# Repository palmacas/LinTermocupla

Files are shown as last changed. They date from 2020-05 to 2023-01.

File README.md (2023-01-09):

# LinTermocupla

LinTermocupla

The board reads the voltaje from a thermocouple (type J or K) and linearizes the temperature. The circuit is based on a PIC16F877a and includes a resistor-based digital-to-analog converter, so the linearized temperature value can be read by a PLC.

---
More information:  
[Linealizar una Termocupla [Spanish]](https://palmacas.com/linealizar-una-termocupla/)

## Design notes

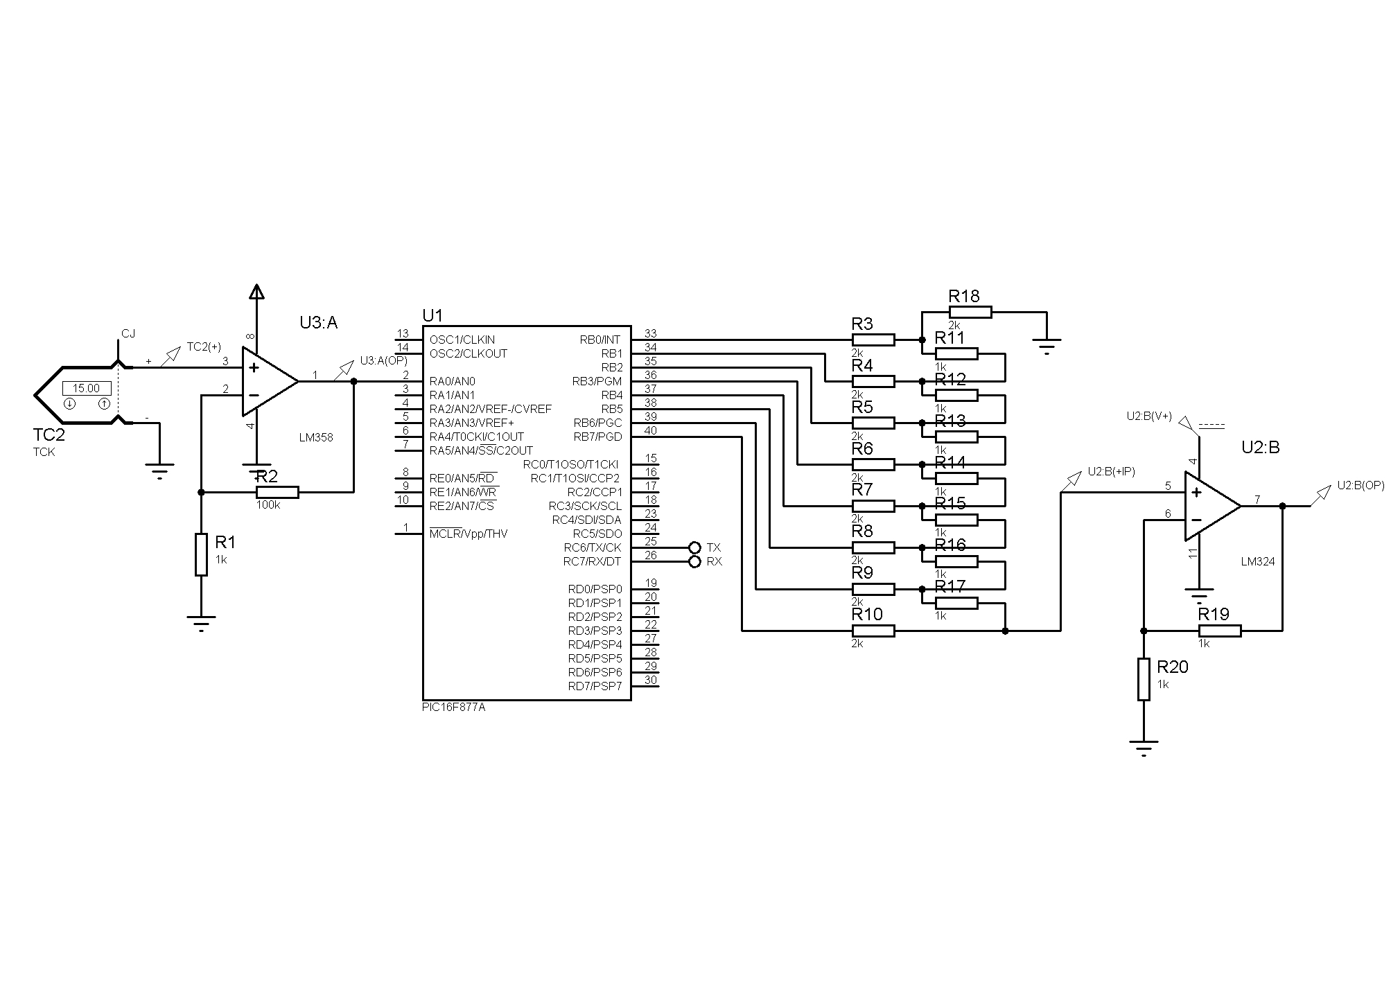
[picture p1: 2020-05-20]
simulation/lin_termocupla.jpg

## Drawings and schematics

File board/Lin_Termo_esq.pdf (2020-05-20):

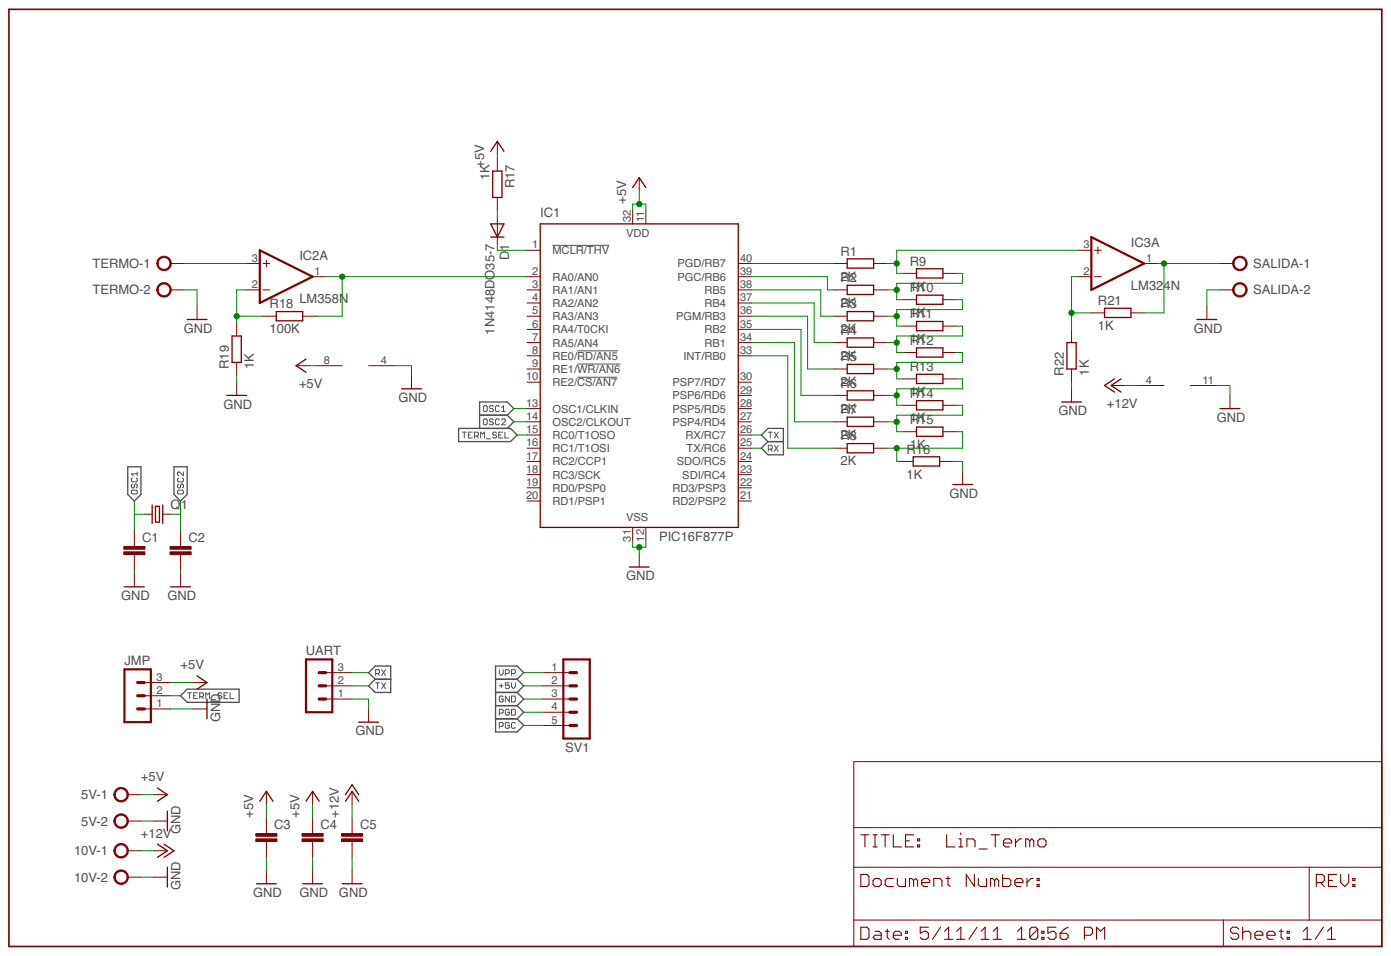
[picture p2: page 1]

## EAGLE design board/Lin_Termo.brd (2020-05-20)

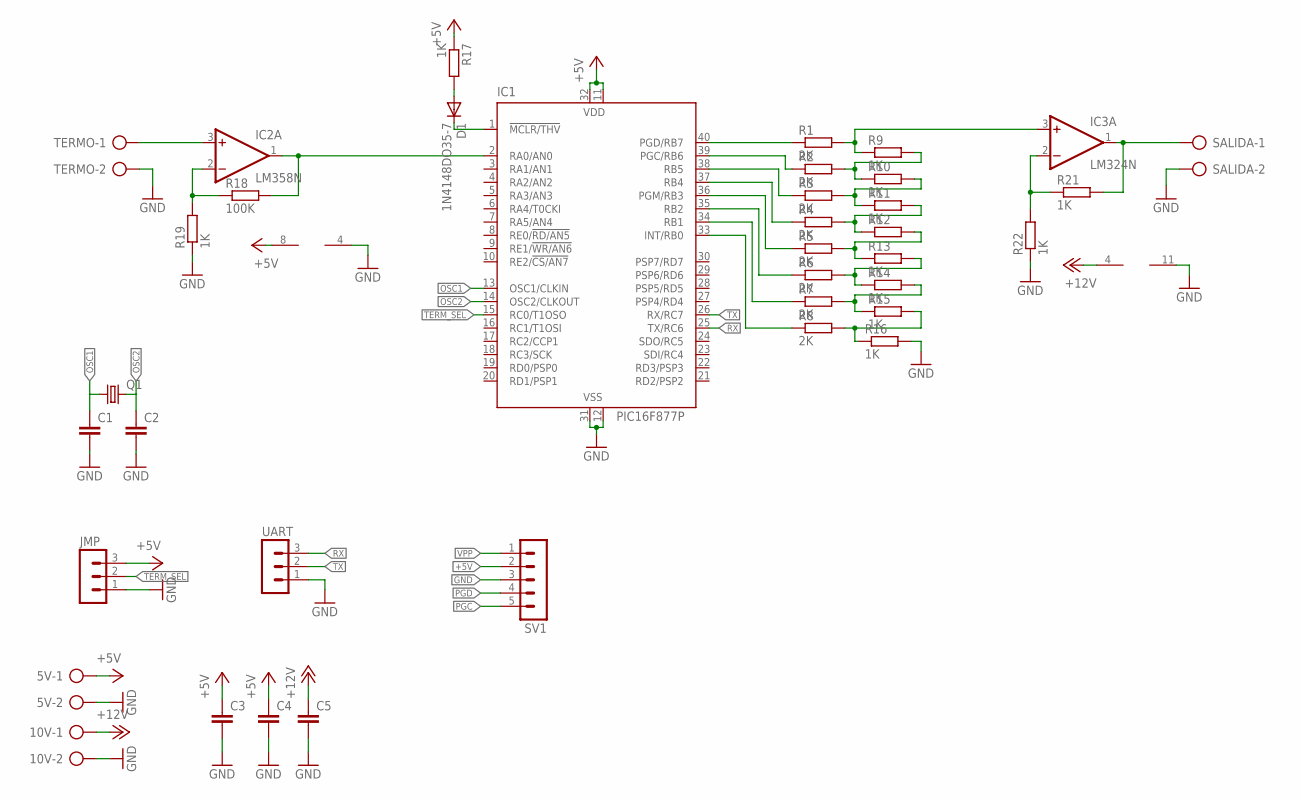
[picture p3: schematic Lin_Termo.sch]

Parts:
5V, 10V: AK500/2
C1, C2, C3, C4, C5: C-EU025-025X050; C025-025X050
D1: 1N4148DO35-7; DO35-7
IC1: PIC16F877P; DIL40
IC2: LM358N; DIL08
IC3: LM324N; DIL14
JMP: MA03-1
Q1: CRYSTALHC49S; HC49/S
R1, R2, R3, R4, R5, R6, R7, R8: 2K; 0207/2V
R9, R10, R11, R13, R14, R15, R16: 1K; 0207/2V
R12: R-EU_0207/2V; 0207/2V
R17, R19, R21, R22: 1K; 0207/7
R18: 100K; 0207/7
SALIDA: AK500/2
SV1: MA05-1
TERMO: AK500/2
UART: MA03-1

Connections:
+5V: 5V.1, C3.1, C4.1, IC1.11 (VDD), IC1.32 (VDD), IC2.8 (V+), JMP.3, R17.1, SV1.2
+12V: 10V.1, C5.1, IC3.4 (V+)
GND: 5V.2, 10V.2, C1.2, C2.2, C3.2, C4.2, C5.2, IC1.12 (VSS), IC1.31 (VSS), IC2.4 (V-), IC3.11 (V-), JMP.1, R16.2, R19.1, R22.1, SALIDA.2, SV1.3, TERMO.2, UART.1
unnamed: IC3.3 (+IN), R1.2, R9.1
unnamed: R2.2, R9.2, R10.1
unnamed: R3.2, R10.2, R11.1
unnamed: R4.2, R11.2, R12.1
unnamed: R5.2, R12.2, R13.1
unnamed: R6.2, R13.2, R14.1
unnamed: R7.2, R14.2, R15.1
unnamed: D1.A, R17.2
unnamed: IC1.38 (RB5), R3.1
unnamed: IC1.37 (RB4), R4.1
unnamed: IC1.36 (PGM/RB3), R5.1
unnamed: IC1.35 (RB2), R6.1
unnamed: IC1.34 (RB1), R7.1
unnamed: IC1.33 (INT/RB0), R8.1
unnamed: IC1.2 (RA0/AN0), IC2.1 (OUT), R18.2
unnamed: IC2.2 (-IN), R18.1, R19.2
unnamed: IC2.3 (+IN), TERMO.1
unnamed: R8.2, R15.2, R16.1
unnamed: IC3.2 (-IN), R21.1, R22.2
unnamed: IC3.1 (OUT), R21.2, SALIDA.1
OSC1: C1.1, IC1.13 (OSC1/CLKIN), Q1.1
OSC2: C2.1, IC1.14 (OSC2/CLKOUT), Q1.2
PGC: IC1.39 (PGC/RB6), R2.1, SV1.5
PGD: IC1.40 (PGD/RB7), R1.1, SV1.4
RX: IC1.25 (TX/RC6), UART.3
TERM_SEL: IC1.15 (RC0/T1OSO), JMP.2
TX: IC1.26 (RX/RC7), UART.2
VPP: D1.C, IC1.1 (!MCLR/THV), SV1.1

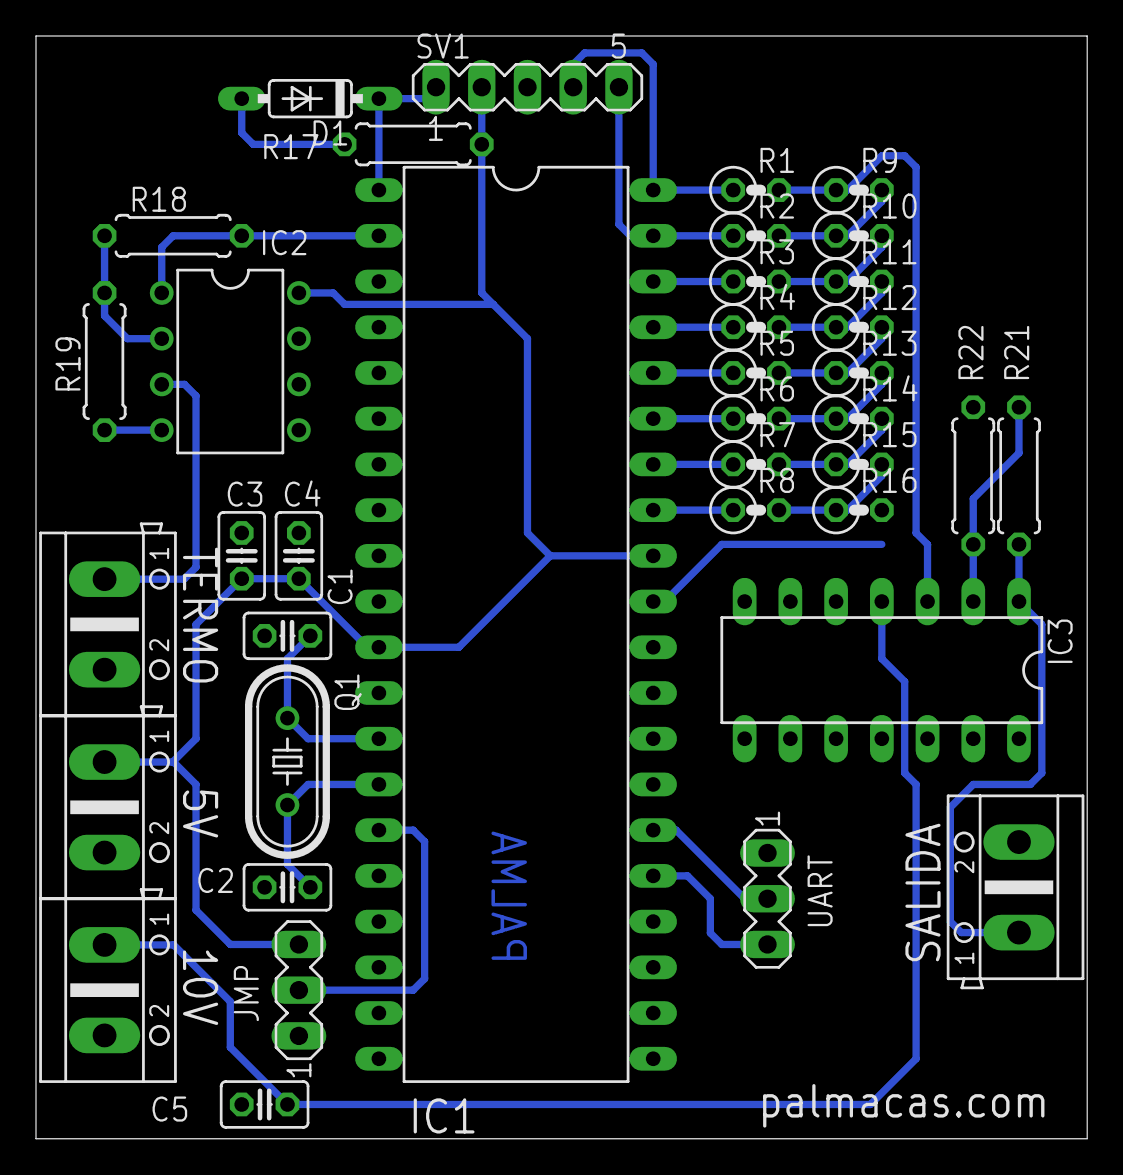
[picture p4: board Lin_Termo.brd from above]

Board: 2 copper layers, 58.4 x 61.3 mm, 38 parts (0 on the bottom side), 31 nets.

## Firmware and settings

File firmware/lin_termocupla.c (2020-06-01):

#INCLUDE <16F877a.H>  //PIC utilizado
#DEVICE ADC = 10
#INCLUDE <MATH.H>    //Libreria con funciones matematicas
#FUSES   NOWDT       //No Watch Dog Timer
#FUSES   XT          //
#FUSES   NOPUT       //No Power Up Timer
#FUSES   NOPROTECT   //Code not protected from reading
#FUSES   NOBROWNOUT  //No brownout reset
#FUSES   NOLVP       //No low voltage prgming, B3(PIC16) or B5(PIC18) used FOR I/O
#FUSES   NOCPD       //No EE protection
#use  delay(clock=4000000)
#use rs232(baud=9600, xmit=pin_c6, rcv=pin_c7, parity=n, bits=8, stop=1)

//Puertos y Registros//
#byte porta = 0x05
#byte portb = 0x06
#byte portc = 0x07

/* Variables */
float vd;   // Voltaje leido por el ADC
float va;   // Voltaje de la temperatura ambiente
float vt;   // Voltaje en la termocupla
float temp; // Temperatura
float a0,a1,a2,a3,a4,a5,a6,a7,a8;

/* Funciones */
void lectura_adc(void);
void tabla_j(void);
void tabla_k(void);

void main()
{
   float vt_mv;
   set_tris_a (0xff);
   set_tris_b (0x00);
   set_tris_c (0xfe);
   portb = 0x00;
   output_high(pin_c0);
   setup_adc (adc_clock_internal);
   setup_adc_ports (an0);
   for(;;)
   {
      lectura_adc(); 
      vt = vd/101;
      vt_mv = vt*1000;      
      if(input(pin_a1)==1)
      {
         tabla_k();
         printf("Voltaje de la termocupla K: %fmV\r\n",vt_mv);
      }
      else
      {
         tabla_j();
         printf("Voltaje de la termocupla J: %fmV\r\n",vt_mv);
      }
      temp = temp + 15;
      if(temp<254)
      {
         portb = temp;
         printf("Temperatura de la temocupla: %fC\r\n",temp);
         delay_ms(1000);
      }
      else
      {
         portb=0xFF;
      }
   }   
}

void lectura_adc(void)
{
   int16 i;
   float vd_mv;
   set_adc_channel(0);
   delay_us(10);
   i = read_adc(adc_start_and_read);   
   printf("Lectura ADC: %ld\r\n",i);
   vd = 5.0*i/1024.0;
   vd_mv = vd*1000;
   printf("Voltaje de la LM324: %fmV\r\n",vd_mv);
}

void tabla_j(void)
{
   a0 = -0.048868252;
   a1 = 19873.14503;       
   a2 = -218614.5353;
   a3 = 11569199.78;      
   a4 = -264917531.4;      
   a5 = 2018441314;   
   temp =a0+vt*(a1+vt*(a2+vt*(a3+vt*(a4+a5*vt))));  
}

void tabla_k(void)
{
   a0 = 0.226584602;
   a1 = 24152.10900;       
   a2 = 67233.4248;
   a3 = 2210340.682;      
   a4 = -860963914.9;      
   a5 = 4.83506E+10;
   a6 = -1.18452E+12;
   a7 = 1.38690E+13;
   a8 = -6.33708E+13;
   temp =a0+vt*(a1+vt*(a2+vt*(a3+vt*(a4+vt*(a5+vt*(a6+vt*(a7+a8*vt)))))));
}
